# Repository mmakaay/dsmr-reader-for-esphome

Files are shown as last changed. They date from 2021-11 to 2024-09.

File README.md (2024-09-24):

# DSMR Reader for ESPHome

A smartmeter integration project, based on the ESP8266 D1 Mini board, made for ESPHome (hardware + ESPHome config).
This device can be used with the energy dashboard that was introduced in Home Assistant 2021.8.0.

The goal of the project is to provide an open source design for an easy to build ESPHome DSMR reader device.

[Made for ESPHome](https://esphome.io/guides/made_for_esphome.html)

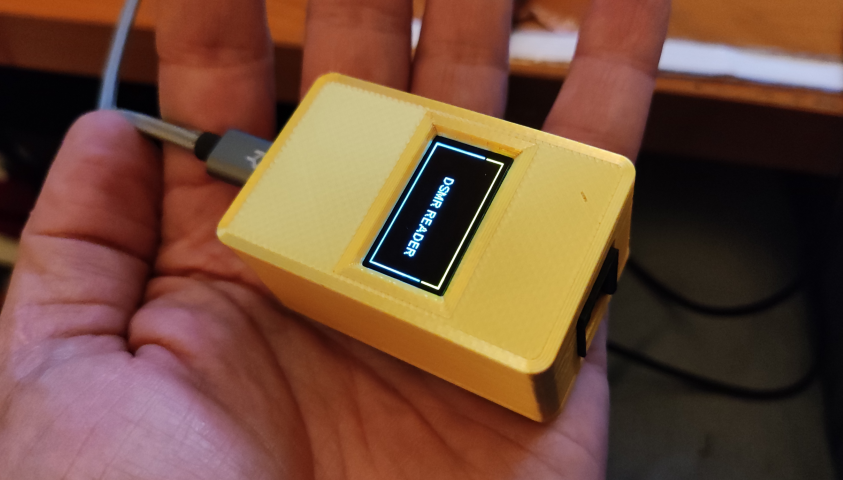
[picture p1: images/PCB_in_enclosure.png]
PCB in enclosure


# Files

* [Schematic](PCB/schematic.png)
* [PCB design](PCB/design.png)
* [Gerber file](PCB/schematic.zip) (can be used for ordering the PCB at for example JLCPCB)
* [ESPHome example configuration](example.yaml)

# Compatibility

The device can be directly powered by the smart meter. This has been tested with DSMR v4 and DSMR v5 meters.

I have a **DSMR v4.2** meter myself, which delivers enough current to power the ESP8266 D1 Mini.
It does require a 1000 uF capacitor though, to handle the power peaks of the D1 Mini during startup and
connecting to the WiFi network.

There are also DSMR v4 meters that don't deliver enough current to run the device. For those meters and
for earlier DSMR versions, it is possible to power the D1 Mini using an external power supply.

Please let me know if you find additional compatibility outcomes.
 
# (*)Note on DSMR v4.2 without using an external power supply

The DSMR4.2 P1 port is current (up to 100 mA) AND voltage regulated (5V). The ESP8266 D1 Mini boards have short term power peaks while connecting to wifi or transmitting over wifi. With low wifi reception the peak draw can be up to 250 mA for 5-15 milisecond. This is exceeding the DSMR v4 P1 port electrical specification by far. In such cases the output voltage of the ESP8266 D1 Mini on board power regulator will drop and result in a reboot. This will happen over and over again. Increasing the capacity of the capacitor significantly can help to overcome this.
Two small 6.3V 3300uF capacitors mounted in parallel instead of the 1000uF in the schematics has been implemented succesfully.
These capacitors are available in Ø 10mm x 25mm and the 1000uF capacitor in the schematics can directly be substituded with one of the two. The second 3300uF capacitor can be mounted piggy-back on the other side of the PCB. The PCB does not have to be altered for this, however it will not fit the current enclosure.

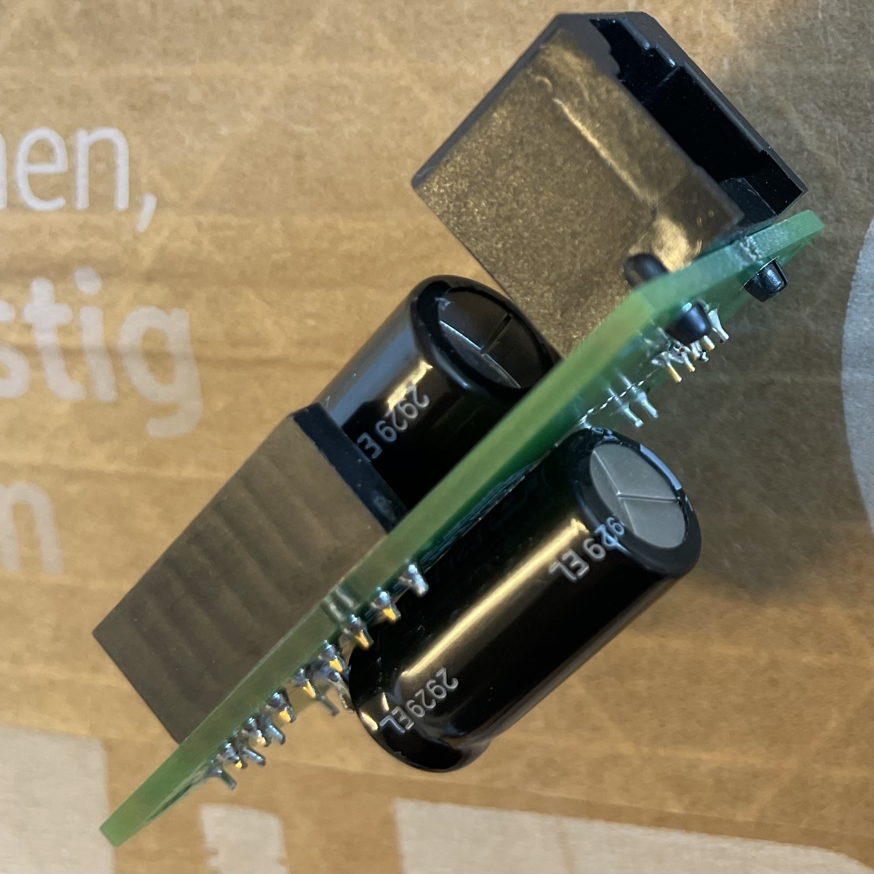
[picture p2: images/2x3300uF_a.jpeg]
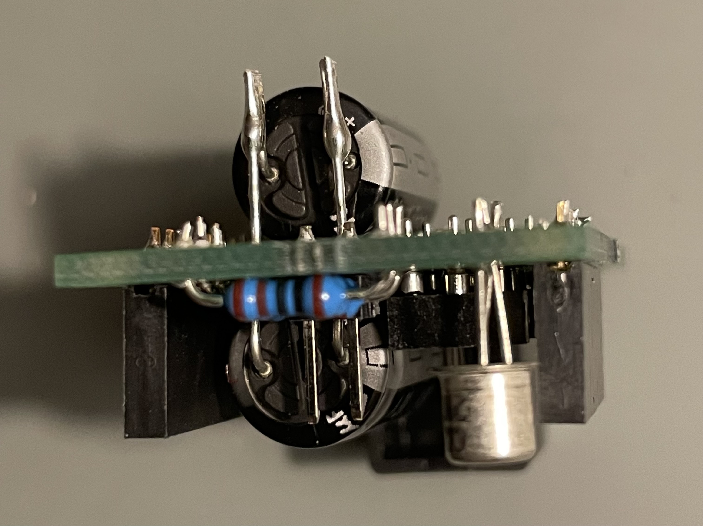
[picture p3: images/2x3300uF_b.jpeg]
 

# Parts list

* 1 x DSMR Reader PCB (can be ordered from a manufacturer like JLCPCB using the Geber file)
* 3 x Resistor 1 kOhm
* 1 x Resistor 200 Ohm
* 1 x Resistor 100 Ohm
* 1 x Transistor 2N2222 TO92
* 1 x Optocoupler 4N35
* 1 x Capacitor 1000 uF (ALTERNATIVE: 2 x 6.3V 3300uF Ø 10mm x 25mm, see (*)Note above)
* 1 x RJ12 socket
* 1 x ESP8266, D1 Mini (with male headers)
* 2 x 8 pin female header (for connecting the D1 mini)
* 2 x 2 pin male header
* 2 x header jumper (fits over the 2 pin male header)
* 1 x RJ12 to RJ12 cable (straight)

**Optionally, for connecting an OLED display**

* 1 x 4 pin female shield stacking header
* 2 x 4 pin male header (of which only the plastic part is used)
* 1 x SSD1306 128x64 I2C OLED display

# Credits

The circuit that I used as a starting point for my board:
https://klushok.etv.tudelft.nl/projects/view?id=8

This one got some nice ideas too:
https://willem.aandewiel.nl/index.php/2019/04/09/dsmr-logger-v4-slimme-meter-uitlezer/

This page had a good collection of info about the P1 port:
http://domoticx.com/p1-poort-slimme-meter-hardware/

Some nice folks that helped me improving the design:
- from the ESPHome discord channel, in alphabetical order:
  Azimath, Frank Bakker, Jos, stoic
- Zoltán Komló

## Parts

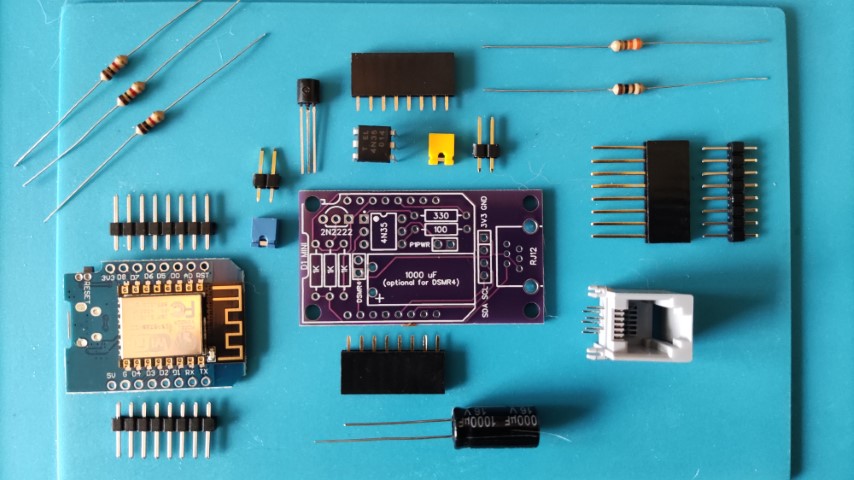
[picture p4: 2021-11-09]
images/build/01_parts.jpg

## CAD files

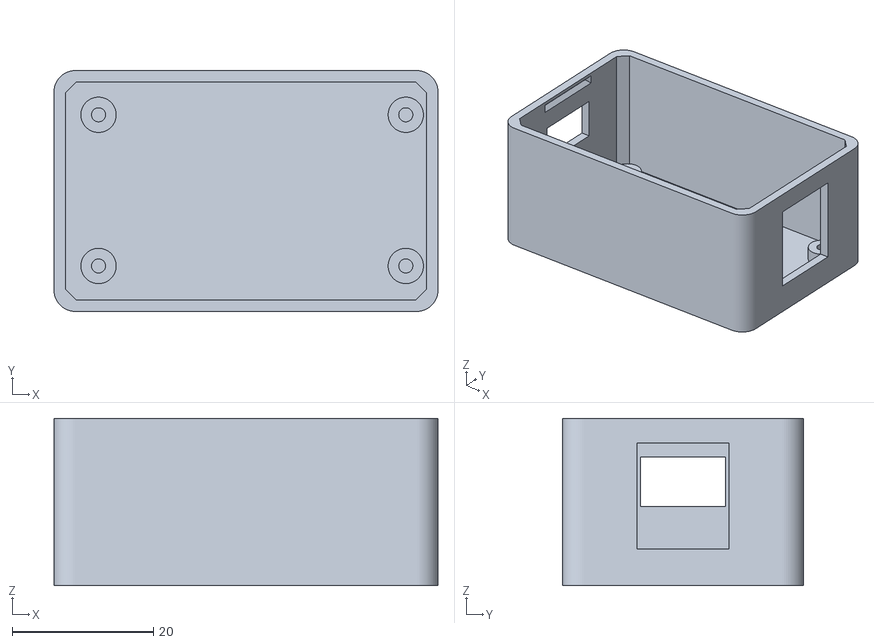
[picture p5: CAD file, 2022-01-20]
enclosure/EnclosureBody.stl
54.4 x 34.1 x 23.7

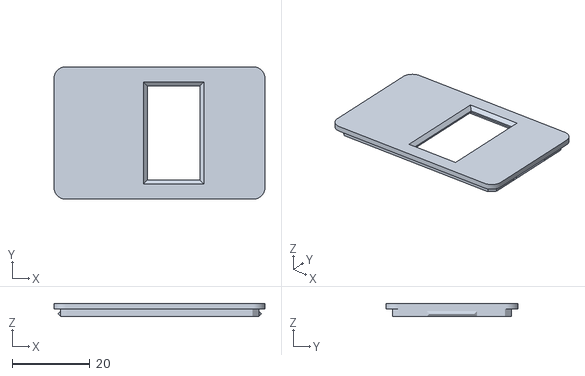
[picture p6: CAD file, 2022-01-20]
enclosure/EnclosureLid.stl
54.4 x 34.1 x 3.40

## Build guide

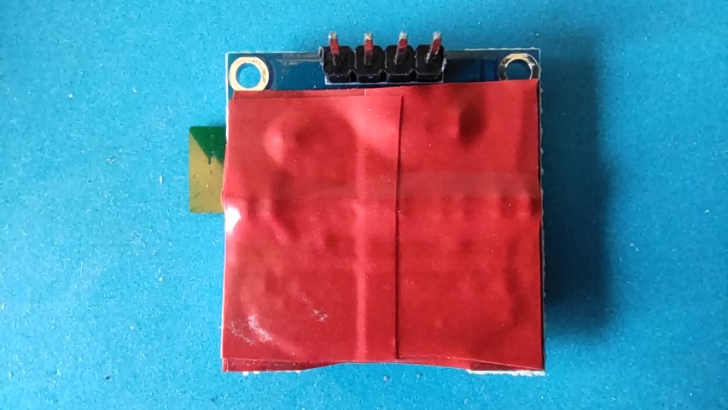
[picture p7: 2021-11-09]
images/build/30_OLED_dispay_c.jpg

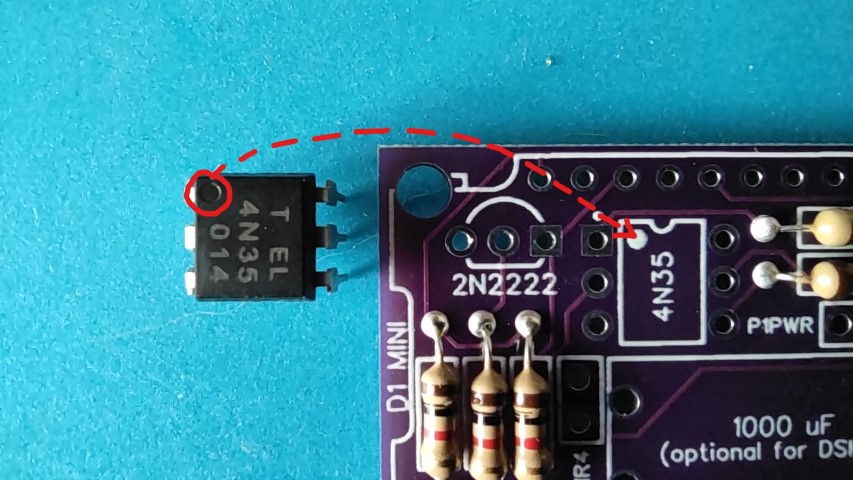
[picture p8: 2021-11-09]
images/build/09_optocoupler_orientation.jpg

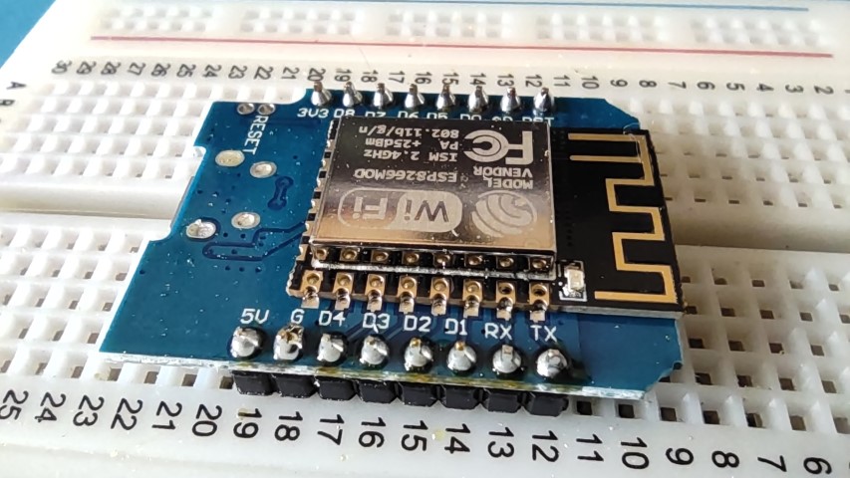
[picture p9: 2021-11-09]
images/build/05_d1_headers_c.jpg

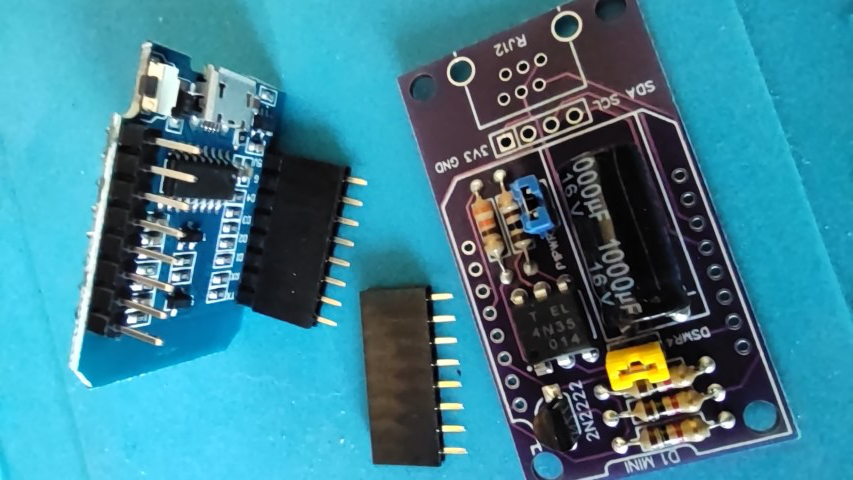
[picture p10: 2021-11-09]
images/build/16_D1_female_headers_a.jpg

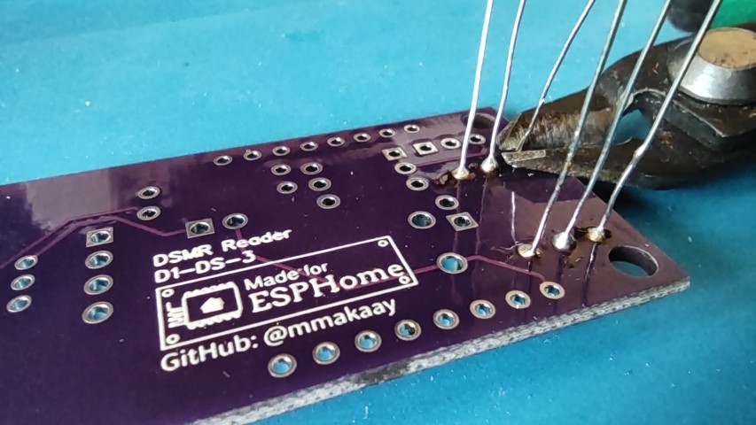
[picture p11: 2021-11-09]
images/build/06_3xresistor_1k_a.jpg

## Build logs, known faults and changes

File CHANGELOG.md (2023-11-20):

# Changelog

## 2023-11-20

* Replaced the 330 Ohm resistor (used as ballast resistor for the optocoupler
  LED) with a 200 Ohm resistor. The initial resistance calculation was based
  on a 5V input, overlooking the fact that the D1 Mini pins output at 3.3V.
  Special thanks to Zoltán Komló for discovering and troubleshooting the issue
  and for proposing the solution.

## 2021-11-06

* Initial release of my DSMR reader for ESPHome, based on the ESP8266 D1 Mini.
* The design uses the "Made for ESPHome" logo, approved by Nabu Casa.
  See: https://esphome.io/guides/made_for_esphome.html
* A few PCB versions and styles were explored, before ending up with this version: D1-DS-3.
  This code indicates the third iteration of a D1 mini-based Display Shield solution.
* Earlier versions did use some SMD components, but those can be a bit of a challenge for people
  with limited soldering tools / skills. Therefore, this version uses only through hole components,
  that are not hard to solder.
* The circuitry provides hardware support for inverting the UART signal, as required for a P1 port.
* It also provides support for enabling and disabling the P1 request data pin. Using this, the
  update interval for the smart meter readings can be cleanly controlled. Also, the data transmissions
  from the smart meter can be suspended after reading a telegram, so no new data will come in during
  processing of the telegram. This is especially useful for those meters that are transmitting data
  every second as long as the request pin is high.
* Optionally, a header can be added for connecting an I2C OLED display.

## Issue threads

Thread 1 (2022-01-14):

STL for Case

laurensvane, 2022-01-14:
Not a real issue, but is it possible to share the stl file for printing the box as shown in the picture?
Would be nice to give it a nice fitting box.

mmakaay, 2022-01-20:
The case is not 100% ready, design-wise, but quite usable as you saw in the picture.
I will upload what I've got so far.

mmakaay, 2022-01-20:
I added my STL files to the project in the enclosure/ folder.

Closed 2022-06-13.

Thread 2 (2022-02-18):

EasyEDA Project

WebSpider, 2022-02-18:
Hi!

The september version of this repo had an EasyEDA project ZIP in it.This was much appreciated :)
Would it be possible to add this again?

mmakaay, 2022-06-13:
I totally missed this request, sorry for that.
I just made a backup export for the EasyEDA project and added it to the repository:
https://github.com/mmakaay/dsmr-reader-for-esphome/blob/main/PCB/EasyEDA_project_backup.zip

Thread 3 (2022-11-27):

ESP32 C3 compatibility

joostbijl, 2022-11-27:
Hi,

Thanks for this nice project!

i've installed a Wemos C3 Mini on top of the pcb. This compiles and seems to work somewhat with the config below. I can connect it to home assistant, but i don't see any values, only ' unknown'.

D1 dsmr alias d5 = gpio 14  >> gpio1 on C3
D1 uart alias d7 = gpio 13  >> gpio4 on C3

Everything loks good, but no data :). Is there something obvious i might be missing? Or is there a way to validate esphome receives the data correctly from the P1 port?

```
substitutions:
  name: dsmr-reader
  friendly_name: DSMR Reader

esphome:
  name: ts27meter
  platformio_options:
    board_build.flash_mode: dio

esp32:
  board: esp32-c3-devkitm-1
  framework:
    type: arduino
    version: 2.0.3
    platform_version: 4.4.0

logger:
  # Serial logging is disabled by setting the logger baud rate to 0.
  # Otherwise the logger will occupy the hardware UART, making it unavailable
  # for receiving smart meter data on pin D7 (GPIO13).
  baud_rate: 0
  level: VERBOSE

# Enable Home Assistant API
api:
  password: "xx"

ota:
  password: ""

wifi:
  ssid: "xx"
  password: "xx"
  output_power: "8.5"

uart:
  rx_pin: GPIO4
  baud_rate: 115200
  rx_buffer_size: 1500

dsmr:
  request_pin: GPIO1
  request_interval: 10s

sensor:
  - platform: dsmr
....
```

joostbijl, 2022-11-27:
allright, that was a user-error - i used the wrong cable. THere's data going to Home Assistant now

Closed 2022-11-27.

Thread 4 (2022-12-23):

Compatibility with the new Resa electric board ?

silkyclouds, 2022-12-23:
Hello there,

Resa called me and they will swap my good old electric counter for a new one. Here is the info I could find about it :

https://www.resa.be/fr/ma-situation/mon-compteur/compteur-communicant/

I guess this will be pretty standard to wat you guys do have in Brussels (I'm living next to Liège), and I'd like to get one of your nice wifi connected boards to connect it to HA.

Is it still something I an buy ?

Please let me know :)

Thanks !

Closed 2023-12-13.

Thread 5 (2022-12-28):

RJ12 Partnumber

Sfunzer, 2022-12-28:
Hi!

An easy/quick one: do you have a part number for the RJ12 socket. I can't seem to find the right one.

Thanks!

thed6bel, 2022-12-30:
Hello,
i ordered this one :

https://fr.aliexpress.com/item/4000252589302.html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

:-)

PexJensen, 2023-03-18:
> Hello, i ordered this one :

And it fits perfectly.

Hoffnungsthal, 2023-11-23:
After a long search I found this one:

https://www.conrad.de/de/p/econ-connect-mjusn66gab-modular-einbaubuchse-mjusn66gab-buchse-einbau-horizontal-pole-6-schwarz-1-st-1311387.html

mmakaay, 2023-12-13:
I ordere mine off Ali. Two different sets. Black and grey ones. The black ones are the hardest to fit on the holes, but they do fit. They grey ones fit perfectly. So I guess as long as the footprint looks like the one on my board design, it should be okay.

Closed 2023-12-13.

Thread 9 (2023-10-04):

Help with hardware

Bl00d-B0b, 2023-10-04:
Hello,

Maybe some one can help me to create a hardware using this project. I need 2-3 units.
preffered with LED, 3D I can print myself. but I prefer to get whole device.

Ed

Closed 2023-11-20.

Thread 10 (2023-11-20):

Wrong value for optocoupler resistor

mmakaay, 2023-11-20:
I received this via a different channel:

"According to your remarks you set the optocoupler's input current to 15mA with a 330 Ohm resistor, which would only be correct if the voltage drop across the resistor would be 5V...
But the ouput voltage of te ESP's pin is 3.3V and the optocoupler's LED has a ~1.1-1.2V voltage drop too. So across the resistor we can calculate only with ~2.1V (In the reality a little less.)
The 330 Ohm resistor sets the input current to ~6mA (measured 5.7mA), which is not enough to my Aliexpess sourced optocouples to drive the meter's data_request pin.
So I recalculated the current limiting resistor value to 200 Ohm, which gives ~9-10mA to the optocoupler' LED and it is working as intended... (15mA would be to high hence the ESP's output current should be limited to 12mA max.)"

mmakaay, 2023-11-20:
I clearly computed the value for that resistor wrong.
This will also have to be updated on the esphome.io DSMR page.

mmakaay, 2023-11-20:
Curious about what I did wrong, I looked up my original computations.
Turns out I indeed wrongly used 5V as the ESP pin's output voltage.
With that voltage, a 1.2V voltage drop and 330 Ohm resulted in 11mA - 12mA of current.

mmakaay, 2023-12-13:
The documentation at the ESPHome site has been updated too, so this issue can be closed now.

Closed 2023-12-13.

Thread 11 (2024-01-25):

Schematic missing

szkrisz, 2024-01-25:
Can you please reupload the schematic.png currently it is unreadable.
Thank You!

wimjanse, 2024-03-09:
same question as above, please re upload the schematic, file seems to be corrupted

mmakaay, 2024-09-24:
I did update the schematic, but forgot to report back here.
The https://github.com/mmakaay/dsmr-reader-for-esphome/blob/main/PCB/schematic.png in its current form should be readable. Feel free to re-open when you still have issues with it.

Closed 2024-09-24.

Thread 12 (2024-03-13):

OLED Example

Bl00d-B0b, 2024-03-13:
hello,

Hello,

Could you please provide yaml example for OLED display?

Ed

Bl00d-B0b, 2024-03-13:
i2c:
  id: bus_a
  sda: D2
  scl: D1
  scan: true

font:
  - file: "fonts/Roboto-Regular.ttf"
    id: tnr1
    size: 17

display:
  - platform: ssd1306_i2c
    reset_pin: D0
    update_interval: 5s
    model: "SSD1306 128x64"
    address: 0x3C
    rotation: 180
    lambda: |-
      // Display current date and time
      it.strftime(64, 0, id(tnr1), TextAlign::TOP_CENTER, "%Y-%m-%d", id(ntp_time).now());
      it.strftime(64, 44, id(tnr1), TextAlign::BASELINE_CENTER, "%H:%M:%S", id(ntp_time).now());

Closed 2024-03-13.

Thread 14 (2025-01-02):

Why is resistor R6 needed?

LarsStegman, 2025-01-02:
Hi, I don't understand why resistor R6 is needed in /PCB/schematic.jpg. Could please explain it to me?

Closed 2025-01-03.

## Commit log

2021-08-28 Updated documentation for latest board version.
2021-09-08 Restructured archive and added 'Made for ESPHome'.
    [enclosure box.stl, enclosure.f3d, enclosure_lid.stl]
2021-11-09 Add information for new D1-DS-3 design.
    [enclosure box.stl, enclosure.f3d, enclosure_lid.stl]
2022-01-20 Added enclosure STL files
    [EnclosureBody.stl, EnclosureLid.stl]
2022-01-21 A few small doc fixes
    - added the required RJ12 cable to the list of parts
    - removed a stale reference to the ESP-01 MCU
    Thanks to @jsuanet for the heads up.
2023-11-20 Replace optocoupler ballast resistor with 200 Ohm
    Replaced the 330 Ohm resistor (used as ballast resistor for the
    optocoupler LED) with a 200 Ohm resistor. The initial resistance
    calculation was based on a 5V input, overlooking the fact that the D1
    Mini pins output at 3.3V.
    Special thanks to Zoltán Komló for discovering and troubleshooting the
    issue and for proposing the solution.
2024-03-11 Updated schematic
2024-09-24 Add files via upload
    2 x 6.3V 3300uF
2024-09-24 Update README.md
    Updated with 2 x 3300uF capacitors for improved power stability on DSMR 4. No change of PCB or schematics needed for this.
